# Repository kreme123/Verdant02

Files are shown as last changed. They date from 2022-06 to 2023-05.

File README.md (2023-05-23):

# Verdant
Verdant is 40% keyboard with OLED and rotary encoder
- Uses Pro Micro 
- Pcb gasket mount
- O-ring gaskets
- Stacked acrylic case
- Rgb underglow

Changes from Verdant 0.1 to 0.2

- More layout support (split space, ansi enter, 2U Lshift)
- Plate
- Smd rgb leds instead of strip
- Acrylic legs

- ### Pics
<a href="https://imgur.com/CjAaG8n">source: imgur.com</a>
<a href="https://imgur.com/gJyBlvI">source: imgur.com</a>
<a href="https://imgur.com/SKLAlS6">source: imgur.com</a>

## 3dp case
<a href="https://imgur.com/uMp8Jgp">source: imgur.com</a>
Unfortunately there's some flaws on 3dp case design, so I don't have plans to release files atm.

- ### Pcb
<a href="https://imgur.com/OcQM3kz">source: imgur.com</a>
- ### Plate
<a href="https://imgur.com/S53nGjT">source: imgur.com</a>
- ### KLE
<a href="https://imgur.com/Mb1c4pH">source: imgur.com</a>
> View on [Keyboard Layout Editor](http://www.keyboard-layout-editor.com/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'&=~%0A%23&_x:1.5&w:2.25%3B&=Enter%3B&@_w:2%3B&=Shift&_x:0.25%3B&=Shift&=%7C%0A%5C&=Z&=X&=C&=V&=B&=N&=M&=%3C%0A,&=%3E%0A.&=%3F%0A%2F%2F&_w:1.25%3B&=Layer&_w:1.25%3B&=Shift%3B&@_x:2.25&w:1.25%3B&=Ctrl&=Layer&_w:1.25%3B&=Alt&_w:7%3B&=7&=%E2%86%90&=%E2%86%91&=%E2%86%93&=%E2%86%92%3B&@_y:0.25&x:2.25&w:1.25%3B&=Ctrl&_a:7%3B&=&=&=&_a:4&w:6.25%3B&=6.25%3B&@_y:0.25&x:6.5&w:2.25%3B&=2.25&_a:7&w:1.25%3B&=&_a:4&w:2.75%3B&=2.75)
> 
https://user-images.githubusercontent.com/85822364/173919702-8fcf09ed-6c48-4af1-a61e-7f3e52898434.mp4

(https://www.paypal.com/donate/?hosted_button_id=BAEE2KMJAVYBW)

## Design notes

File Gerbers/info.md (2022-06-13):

Gerbers for PCB. Sometimes you must add dimensions manually when ordering from JLCPCB.

PCB 319.1 mm * 88.1 mm

Plate 277.2 mm * 77.2 mm

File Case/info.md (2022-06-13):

Use these files to laser cut your case. All layers use 3mm thick acrylic.

Case in the pictures uses iridescent acrylic on top and bottom layer, everything else is clear acrylic.

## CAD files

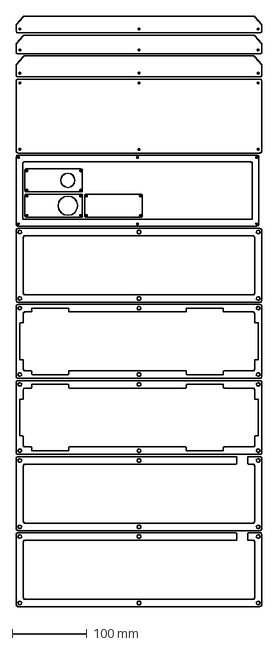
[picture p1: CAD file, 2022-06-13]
Case/Case all.dxf
330.1 x 792.3 mm

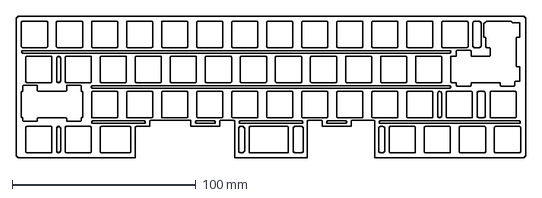
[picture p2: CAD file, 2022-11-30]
Verdant02plate.dxf
277.2 x 77.2 mm

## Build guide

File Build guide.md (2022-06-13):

# Build guide
<a href="https://imgur.com/TLqzrHB">source: imgur.com</a>
## Materials
- 17 x [M2x8mm screws](https://www.aliexpress.com/item/1005002655776515.html)
- 3  x [M2x16mm screws](https://www.aliexpress.com/item/1005002655776515.html)
- 10 x [M2x14mm standoffs](https://www.aliexpress.com/item/1005001478301407.html?spm=a2g0s.9042311.0.0.52114c4dn6suyl)
- ~50 [1N4148 SOD-123 Diode](https://www.aliexpress.com/item/1005002383505485.html)
- 6 x [32mm (OD) x 2.4mm O-rings](https://www.aliexpress.com/item/32908087735.html?spm=a2g0o.order_list.0.0.60cf1802kyAhZY)
- [OLED](https://www.aliexpress.com/item/32896971385.html?spm=a2g0o.order_list.0.0.4c291802RJLFPs)
- [EC11 rotary encoder](https://www.aliexpress.com/item/10000056483250.html?spm=a2g0s.9042311.0.0.52114c4dn6suyl)
- [Encoder knob](https://www.aliexpress.com/item/1005002683252060.html?spm=a2g0o.order_list.0.0.5b901802I6F5Fy)
- [Silicone rubber feet](https://www.aliexpress.com/item/4000439059508.html?spm=a2g0s.9042311.0.0.52114c4dn6suyl)
- [WS2812B 5050 RGB LED](https://www.aliexpress.com/item/1005002653014067.html) (13 leds for one Verdant) 
- [Pro Micro](https://www.aliexpress.com/item/32768308647.html?spm=a2g0o.productlist.0.0.20f5f2022mgoaF)

### Also
- Soldering iron and solder
- Hex/Phillips screwdriver
- Flush side cutters
- ~50 MX style switches
- 7u/6.25u and 2u PCB mount stabilizers
- Keycaps (check compatibility)

## Building

Connect Pro Micro to computer and flash "verdant02_default.hex" firmware using qmk toolbox
<a href="https://imgur.com/jdxeeJ3">source: imgur.com</a>

Solder diodes for all keys. Stripe on diode to square pad on pcb
<a href="https://imgur.com/MtKJaaT">source: imgur.com</a>

If you want to use encoder, solder jump wires from Pro Micro to PCB

I added small amount of solder to pro micro, then placed wire there with heat.
https://golem.hu/guide/pro-micro-upgrade/
<a href="https://imgur.com/X1dGvDT">source: imgur.com</a>

Solder Pro Micro to top side of pcb. Check that pins match.
<a href="https://imgur.com/q7Z4lCL">source: imgur.com</a>

Add rotary encoder (optional)
<a href="https://imgur.com/wUKRIoT">source: imgur.com</a>

Add OLED to top of Pro Micro (optional). Use something like electrical tape between back of oled and top of pro micro to avoid unwanted connection.
<a href="https://imgur.com/F4qzcHS">source: imgur.com</a>

You can also solder OLED here (one oled for one pcb)
<a href="https://imgur.com/1wEgQ8r">source: imgur.com</a>

Solder switches and add stabilizers. Plate is optional
<a href="https://imgur.com/zlWPLtL">source: imgur.com</a>

Solder rgb leds (optional). !!Check that led is correct way!! (triangle goes top left). 
<a href="https://imgur.com/brBb3Zk">source: imgur.com</a>

Add acrylic cover to pcb using screws and standoffs.
<a href="https://imgur.com/zRdwAo9">source: imgur.com</a>

Add O-ring gaskets
<a href="https://imgur.com/kpHrTg5">source: imgur.com</a>

Here's how it should look now
<a href="https://imgur.com/WXYDwvR">source: imgur.com</a>
<a href="https://imgur.com/5AfWyU4">source: imgur.com</a>

## Case

Put screws from the bottom and add standoffs. 
<a href="https://imgur.com/yR1E0yH">source: imgur.com</a>

Add case layers 2-4
<a href="https://imgur.com/j69BH8Q">source: imgur.com</a>

Add soldered pcb.
<a href="https://imgur.com/LDjGZde">source: imgur.com</a>

Add rest of the case layers 5-7 and screw it in.
<a href="https://imgur.com/hOjfyCq">source: imgur.com</a>

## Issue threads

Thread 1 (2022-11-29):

About Verdant 02 License

saoeee, 2022-11-29:
Hello Mr. Kreme, I am a student from China, my friends and I love your Verdant 02 very much and hope to get your authorization to support this non-profit project! We also hope that you can provide a hot swappable solution! If you can, I hope you can provide PCB schematic and PCB source files, thank you!！This is my email：qy735508@126.com  3243079485@qq.com

kreme123, 2022-11-30:
Hi. Feel free to use these files for your project. I don't have plans to make hotswappable version. I will upload PCB and plate source files to github soon. You can use those files to modify hotswap version if needed.

saoeee, 2022-11-30:
Can you tell me your email? I want to get in touch with you better！

saoeee, 2022-11-30:
Can you tell me your email? I would like to get in touch with you better！！I have some keyboard knowledge that I would like to ask you about! Thank you!

kreme123, 2022-11-30:
I sent you an email to qy735508@126.com

saoeee, 2022-11-30:
I'm sorry, I mistyped this email, it should be qy7355608@126.com

Closed 2022-11-30.

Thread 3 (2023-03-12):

hex burnin fail

zaglaw, 2023-03-12:
hello, I downloaded a fw file from,[verdant02_vial.hex](https://github.com/kreme123/Verdant02/blob/main/FirmwareVIAL/verdant02_vial.hex)
trying to flash in promicro by qmktoolbox,
there is somthing wrong but i don't know how to fix it.
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
**> avrdude.exe: invalid record at line 88 of "F:\账户文件\verdant02_vial.hex"
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

zaglaw, 2023-03-12:
direct download filefrom github cause the problem，re git file then fix it

Closed 2023-03-12.

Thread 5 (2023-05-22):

Verdant02 case issue

zaglaw, 2023-05-22:
Hi Kreme,
I am a customer（sort of）,bought Verdant02 with a very fair price from [saoee].#1
Althought, I had been through time issue(dely dely dely). I finally got my Verdant02. It's really pretty.

Still,I (actually we, a group people bought verdant02 from saoee.) found some issue.

99% type-c cable will bent the case.

Now saoee try to solve it by cutting one more layer to make more space.

And I wonder may be we could solve by change the material from PMMA to 3D printing.

I looked up old version, then I found there is some issue on your 3D case file.

May be we could work on it and make verdant02 more  perfect with a 3D-Printing Case version?

PS： I just a normal keyboard user, not a developer. not EE not layout engineer.

kreme123, 2023-05-22:
Hi,

Cutout for the cable is pretty tight. https://vi.aliexpress.com/item/1005003040504687.html I've used this without problems. Height of this cable is ~5mm and the cutout on the case is ~6mm.

Unfortunately that 3d printed case I made had too many problems so it needs complete redesign

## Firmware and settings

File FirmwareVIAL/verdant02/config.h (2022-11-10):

// Copyright 2022 kreme
// SPDX-License-Identifier: GPL-2.0-or-later

#pragma once

#include "config_common.h"

/* USB Device descriptor parameter */
#define VENDOR_ID       0xFEED
#define PRODUCT_ID      0x0000
#define DEVICE_VER      0x0001
#define MANUFACTURER    kreme
#define PRODUCT         verdant02

/* key matrix size */
#define MATRIX_ROWS 8
#define MATRIX_COLS 7

/*
 * Keyboard Matrix Assignments
 *
 * Change this to how you wired your keyboard
 * COLS: AVR pins used for columns, left to right
 * ROWS: AVR pins used for rows, top to bottom
 * DIODE_DIRECTION: COL2ROW = COL = Anode (+), ROW = Cathode (-, marked on diode)
 *                  ROW2COL = ROW = Anode (+), COL = Cathode (-, marked on diode)
 *
 */
#define MATRIX_ROW_PINS { D2, B4, F7, D7, D4, E6, B3, B1 }
#define MATRIX_COL_PINS { C6, F6, B5, D3, B6, F4, F5 }

#define DIODE_DIRECTION COL2ROW

#define ENCODERS_PAD_A \
    { B0 }
#define ENCODERS_PAD_B \
    { D5 }
#define ENCODER_RESOLUTION 4
#define ENCODER_DIRECTION_FLIP
#define TAP_CODE_DELAY 10

#define OLED_TIMEOUT 120000
#define OLED_BRIGHTNESS 120

// reduce memory
#undef LOCKING_SUPPORT_ENABLE
#undef LOCKING_RESYNC_ENABLE
#define NO_ACTION_ONESHOT
#define LAYER_STATE_8BIT

#define RGB_DI_PIN B2
#ifdef RGB_DI_PIN
#define RGBLED_NUM 13
#define RGBLIGHT_HUE_STEP 8
#define RGBLIGHT_SAT_STEP 8
#define RGBLIGHT_VAL_STEP 8
#define RGBLIGHT_LIMIT_VAL 255 /* The maximum brightness level */
#define RGBLIGHT_SLEEP  /* If defined, the RGB lighting will be switched off when the host goes to sleep */
 /*== all animations enable ==*/
//#define RGBLIGHT_ANIMATIONS
// /*== or choose animations ==*/
//     #define RGBLIGHT_EFFECT_BREATHING
//     #define RGBLIGHT_EFFECT_RAINBOW_MOOD
     #define RGBLIGHT_EFFECT_RAINBOW_SWIRL
//     #define RGBLIGHT_EFFECT_SNAKE
//     #define RGBLIGHT_EFFECT_KNIGHT
//     #define RGBLIGHT_EFFECT_CHRISTMAS
//     #define RGBLIGHT_EFFECT_STATIC_GRADIENT
//     #define RGBLIGHT_EFFECT_RGB_TEST
//     #define RGBLIGHT_EFFECT_ALTERNATING
#endif

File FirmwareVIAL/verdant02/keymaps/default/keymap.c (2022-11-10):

/* Copyright 2022 Kreme
 *
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
 * You should have received a copy of the GNU General Public License
 * along with this program.  If not, see <http://www.gnu.org/licenses/>.
 */

#include QMK_KEYBOARD_H
#include <stdio.h>
char wpm_str[10];

oled_rotation_t oled_init_user(oled_rotation_t rotation) { return OLED_ROTATION_180; }

const uint16_t PROGMEM keymaps[][MATRIX_ROWS][MATRIX_COLS] = {

    [0] = LAYOUT(
        KC_DEL,  KC_Q,    KC_W,    KC_E,    KC_R,    KC_T,    KC_Y,    KC_U,    KC_I,    KC_O,    KC_P,    KC_LBRC, KC_RBRC, KC_ENT,
        KC_TAB,  KC_A,    KC_S,    KC_D,    KC_F,    KC_G,    KC_H,    KC_J,    KC_K,    KC_L,    KC_SCLN, KC_QUOT, KC_HASH,
        KC_LSFT, KC_BSLS, KC_Z,    KC_X,    KC_C,    KC_V,    KC_B,    KC_N,    KC_M,    KC_COMM, KC_DOT,  KC_SLSH, MO(1),   KC_RSFT,
        KC_LCTL, KC_LGUI, MO(2),   KC_LALT, KC_SPC,  KC_SPC,  MO(1),   KC_BSPC, KC_LEFT, KC_DOWN, KC_UP,   KC_RGHT, KC_MUTE
    ),

    [1] = LAYOUT(
        KC_ESC,  KC_1,    KC_2,    KC_3,    KC_4,    KC_5,    KC_6,    KC_7,    KC_8,    KC_9,    KC_0,    KC_MINS, KC_EQL,  KC_BSPC,
        KC_LGUI, KC_F1,   KC_F2,   KC_F3,   KC_F4,   KC_F5,   KC_F6,   KC_F7,   KC_F8,   KC_F9,   KC_F10,  KC_F11,  KC_F12,
        _______, _______, RGB_TOG, RGB_MOD, _______, _______, _______, _______, _______, _______, _______, _______, _______, RESET,
        _______, _______, _______, _______, _______, _______, _______, _______, _______, _______, _______, _______, _______
    ),

    [2] = LAYOUT(
        _______, _______, _______, KC_END,  _______, _______, _______, _______, KC_INS,  _______, KC_PSCR, _______, _______, _______,
        _______, _______, _______, KC_DEL,  _______, _______, KC_HOME, _______, _______, _______, _______, _______, _______,
        _______, _______, _______, _______, _______, _______, _______, _______, _______, _______, _______, _______, _______, _______,
        _______, _______, _______, _______, _______, _______, _______, _______, _______, KC_PGDN, KC_PGUP, _______, _______
    ),

};

#if defined(ENCODER_MAP_ENABLE)
const uint16_t PROGMEM encoder_map[][NUM_ENCODERS][2] = {
    [0] = { ENCODER_CCW_CW(KC_VOLD, KC_VOLU)  },
    [1] = { ENCODER_CCW_CW(KC_VOLD, KC_VOLU)  },
    [2] = { ENCODER_CCW_CW(KC_VOLD, KC_VOLU)  }
};
#endif

void matrix_init_user(void) {}

void matrix_scan_user(void) {}

bool process_record_user(uint16_t keycode, keyrecord_t *record) { return true; }

void led_set_user(uint8_t usb_led) {
    if (usb_led & (1 << USB_LED_NUM_LOCK)) {
    } else {
    }

    if (usb_led & (1 << USB_LED_CAPS_LOCK)) {
    } else {
    }

    if (usb_led & (1 << USB_LED_SCROLL_LOCK)) {
    } else {
    }

    if (usb_led & (1 << USB_LED_COMPOSE)) {
    } else {
    }

    if (usb_led & (1 << USB_LED_KANA)) {
    } else {
    }
}

// OLED STUFF STARTS HERE
// based on https://github.com/qmk/qmk_firmware/blob/master/keyboards/kyria/keymaps/j-inc/keymap.c

// In your rules.mk make sure you have:
// OLED_ENABLE = yes
// WPM_ENABLE = yes

#ifdef OLED_ENABLE
// WPM-responsive animation stuff here
#    define IDLE_FRAMES 5
#    define IDLE_SPEED 20  // below this wpm value your animation will idle

// #define PREP_FRAMES 1 // uncomment if >1

#    define TAP_FRAMES 2
#    define TAP_SPEED 40  // above this wpm value typing animation to trigger

#    define ANIM_FRAME_DURATION 200  // how long each frame lasts in ms
// #define SLEEP_TIMER 60000 // should sleep after this period of 0 wpm, needs fixing
#    define ANIM_SIZE 636  // number of bytes in array, minimize for adequate firmware size, max is 1024

uint32_t anim_timer         = 0;
uint32_t anim_sleep         = 0;
uint8_t  current_idle_frame = 0;
// uint8_t current_prep_frame = 0; // uncomment if PREP_FRAMES >1
uint8_t current_tap_frame = 0;

// Code containing pixel art, contains:
// 5 idle frames, 1 prep frame, and 2 tap frames
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

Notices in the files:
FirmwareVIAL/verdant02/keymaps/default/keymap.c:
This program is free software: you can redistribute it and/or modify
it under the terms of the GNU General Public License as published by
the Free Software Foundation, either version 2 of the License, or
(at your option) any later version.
